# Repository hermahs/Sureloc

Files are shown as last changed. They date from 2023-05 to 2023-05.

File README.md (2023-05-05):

# SureLoc: Trust-Based Lending System

SureLoc is an open source project that provides a trust-based lending system for keeping track of who has taken out a certain physical item, called "SureLoc". The system allows users to borrow and lend SureLocs among themselves, while keeping a log of who has borrowed each item and for how long. This can help build trust and accountability among community members who share resources, especially in contexts where formal lending systems may not exist or may be difficult to access.

## Features

- User accounts: Users can create an account to participate in the lending system, and log in securely using their credentials.
- Item borrowing: Users can borrow SureLocs from other users, and keep track of who has borrowed each item.
- Item lending: Users can lend their own SureLocs to other users, and keep track of who has borrowed each item and for how long.
- Item history: The system keeps a log of all borrowing and lending activity for each SureLoc, including the borrower's name, the lending date, and the expected return date.
- Trust ratings: Users can rate each other based on their reliability as borrowers or lenders, and this rating can help other users decide whether to lend or borrow from them in the future.

## Technology

SureLoc is a student project that was developed using Arduino technology. The project uses RFID technology to identify the SureLocs, and an Arduino microcontroller to communicate with the RFID reader and log the borrowing and lending activity.

Please note that due to time constraints and limited resources, the project may not have all the features or functionality that a full-fledged system may have. However, we welcome contributions from anyone interested in helping to develop and improve SureLoc!

## Contributing

If you'd like to contribute to SureLoc, please take a look at our `CONTRIBUTING.md` file for guidelines on how to get started.

## License

SureLoc is licensed under the MIT License. See `LICENSE.md` for more information.

## Getting Started

To get started with SureLoc, follow these steps:

### Needed Components

Before you can use SureLoc, you'll need to gather the following components:

#### Control Box Components

| Component | Quantity |
|---|---:|
| Arduino Uno v3 | 1 |
| RC522 RFID Reader | 1 |
| 12v Power Adapter | 1 |
| Buck Converter | 1 |
| 100k ohm resistor | 1 |
| SD card module | 1 |
| SD card | 1 |
| Breadboard | 1 |
| Barrel jack | 1 |
| 16x2 LCD screen |  (optional) |
| Rotary encoder |  (optional) |

#### Lending Module Components

| Component | Quantity |
|---|---:|
| Arduino Pro Micro | 1 |
| Servo | 1 |
| Small push press button | 2 |
| Transistors | 2 |
| 10k ohm resistor | 2 |
| 1k ohm resistor | 2 |
| Breadboard | 1 |
| Loadcell 5kg |  (optional) x 4 |
| Loadcell amplifier |  (optional) x 4 |

#### Parts Needed to be Printed

The following parts need to be 3D printed or laser cut:

##### Shelf module

| Part | Quantity |
|---|---:|
| Frame Left | 1 |
| Frame Right | 1 |
| Lock Container | 1 |
| Moon lock | 1 |
| Gears | 2 |
| Frame Rails | 4 |
| Drawer Rails | 4 |
| Drawer | 2 |
| Drawer lock holder | 2 |
| Clips Large | 2 |
| Clips Small | 2 |
| Breadboard holder | 1 |

##### Control box

| Part | Quantity |
|---|---:|
| Top hull | 1 |
| Bottom plate | 1 |
| Front plate | 1 |
| Breadboard holder | 1 |
| RFID card reader | 1 |

Note that the box parts can also be laser cut in wood if you have the capability.

Please note that these components are not included in the SureLoc package and must be acquired separately.

## Assembly of the control box and shelf module

### Shelf Module Assembly Guide

1. Insert the clips into one side of the frame.
2. If you are using load cells, screw them into the frame with a little bit of space between them.
3. Insert the servo and moon lock into the lock container.
4. Screw the gears to the servo and moon lock.
5. Combine the frames with the lock container in the middle.
6. Add the rails to the frames.
7. Assemble the drawers.
8. Connect the wires and add the breadboard to the breadboard holder.

### Control Box Assembly Guide

1. Add the breadboard holder to the base plate.
2. Screw the RFID card reader into its holder on the front plate.
3. Attach the screen and rotary encoder to the front plate.
4. Add the buck converter and barrel jack for power.
5. Assemble the top hull over the base plate and screw together.

Note: This is a general guide for assembly and may not include all necessary steps.

## Assembly of the electrical systems

For the assembly of the electrical system, see the images below:

### Control Box

[Control Box Diagram](https://github.com/hermahs/Sureloc/blob/724dfc568ab8b7403ac2a49ec040952a4f51c85d/ControlBox%20Diagram.png)

### Shelf module

[Shelf Module Diagram](https://github.com/hermahs/Sureloc/blob/724dfc568ab8b7403ac2a49ec040952a4f51c85d/ShelfModule.png)

## Installing the Software

Once you have all the necessary components, you can install the SureLoc software on your Arduino microcontroller. To do this, follow these steps:

1. Download the SureLoc code from the GitHub repository.
2. Open the code in the Arduino IDE.
3. Connect the microcontroller to your computer via USB.
4. Upload the code to the microcontroller using the Arduino IDE.

## Support

If you encounter any issues or have questions about using SureLoc, please feel free to create a GitHub issue. We're here to help and improve the system together!

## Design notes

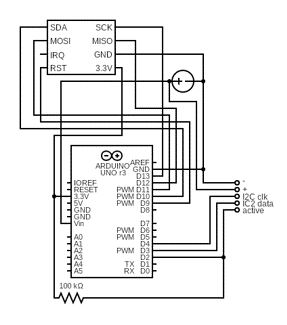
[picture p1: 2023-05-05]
ControlBox Diagram.png

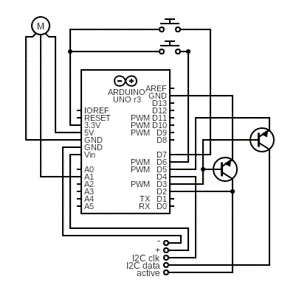
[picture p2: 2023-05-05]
ShelfModule.png

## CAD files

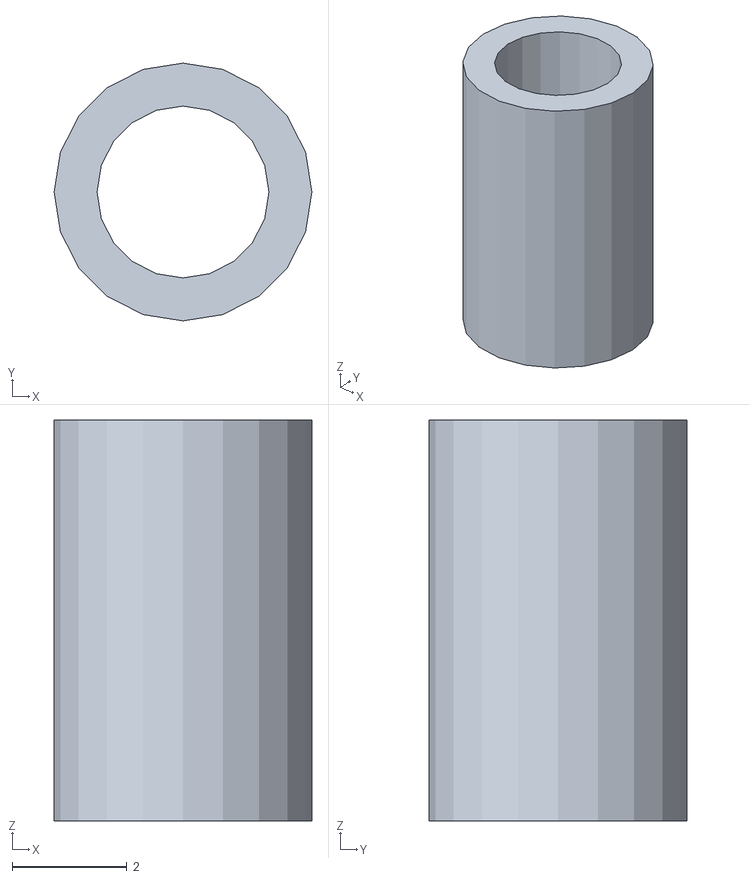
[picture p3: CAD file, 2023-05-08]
models/Control box/Spacers.stl
4.50 x 4.50 x 7.00

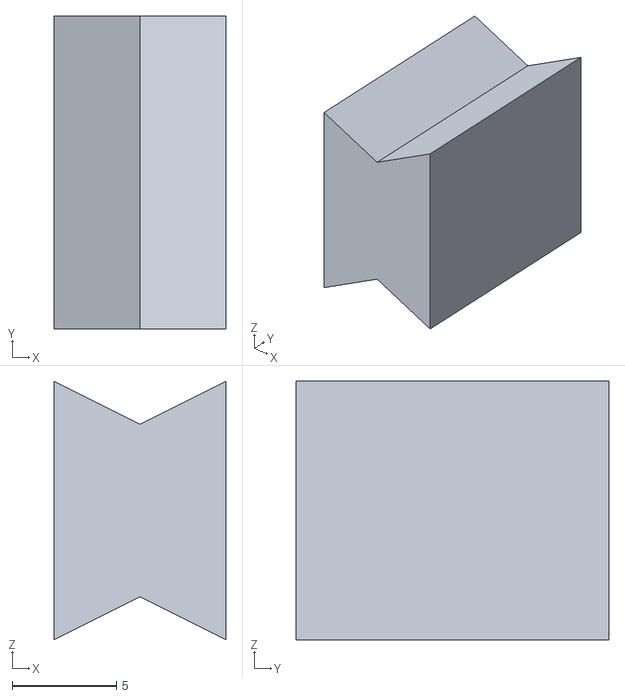
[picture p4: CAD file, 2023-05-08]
models/Shelf module/Wall Mount Rail Connector.stl
8.24 x 15.0 x 12.4

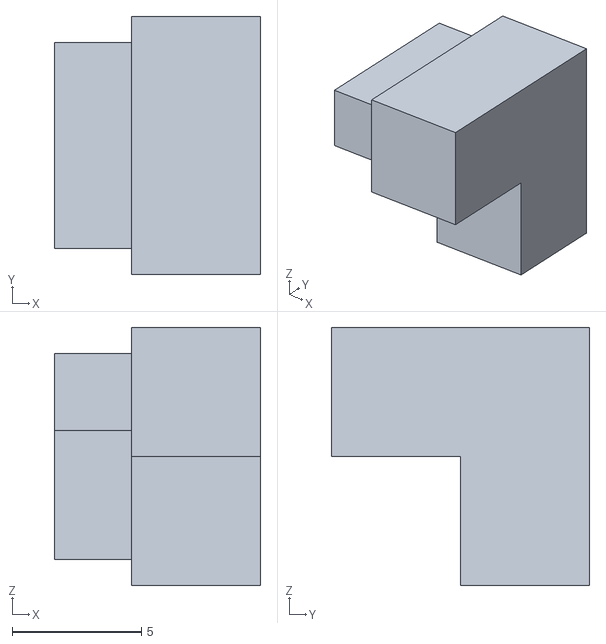
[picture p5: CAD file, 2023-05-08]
models/Shelf module/walls/Frame to Wall Connector.stl
8.00 x 10.0 x 10.0

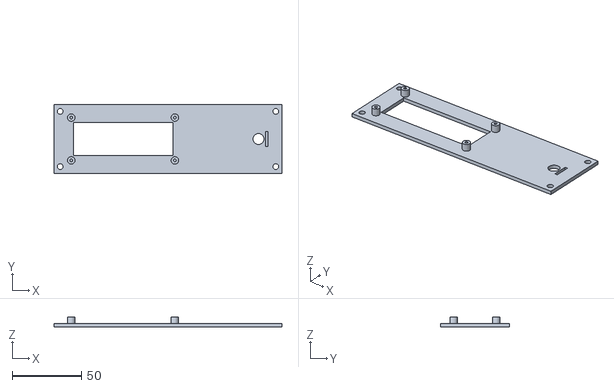
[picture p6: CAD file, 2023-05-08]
models/Control box/Front plate.stl
165.0 x 50.0 x 7.50

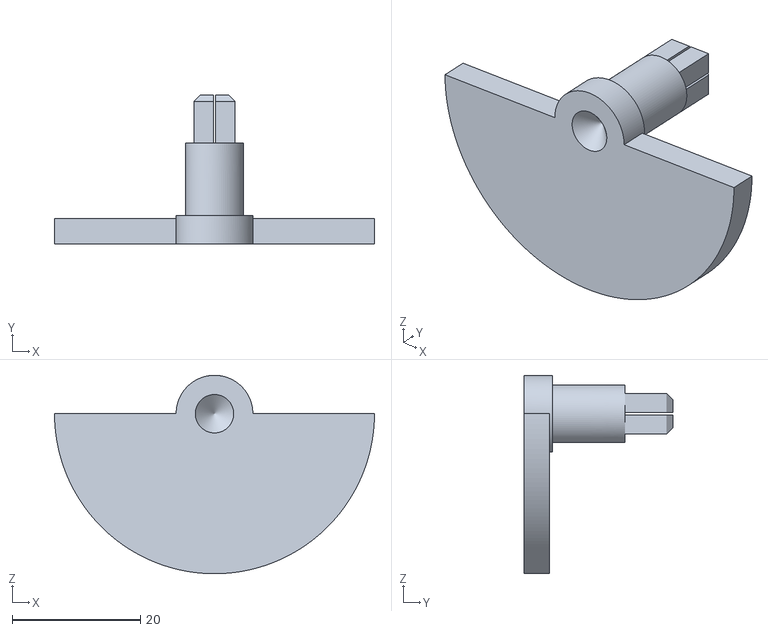
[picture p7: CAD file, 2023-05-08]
models/Shelf module/Moon Lock.stl
50.0 x 23.3 x 31.0

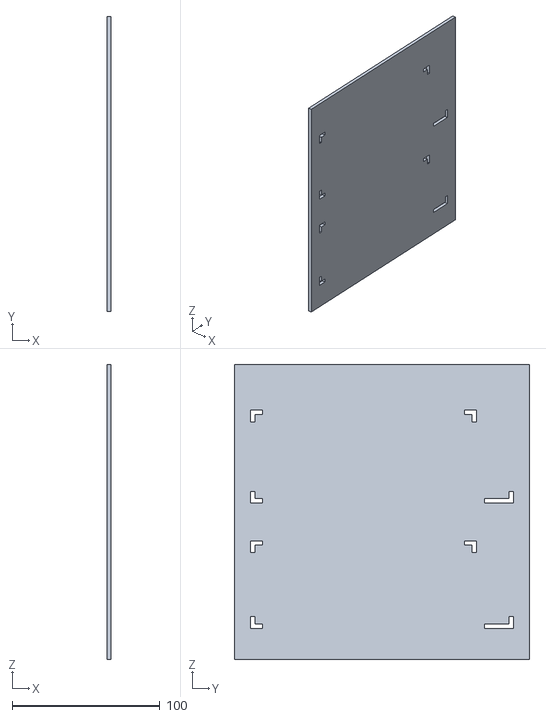
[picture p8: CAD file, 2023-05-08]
models/Shelf module/walls/Wall.stl
3.00 x 200.0 x 200.0

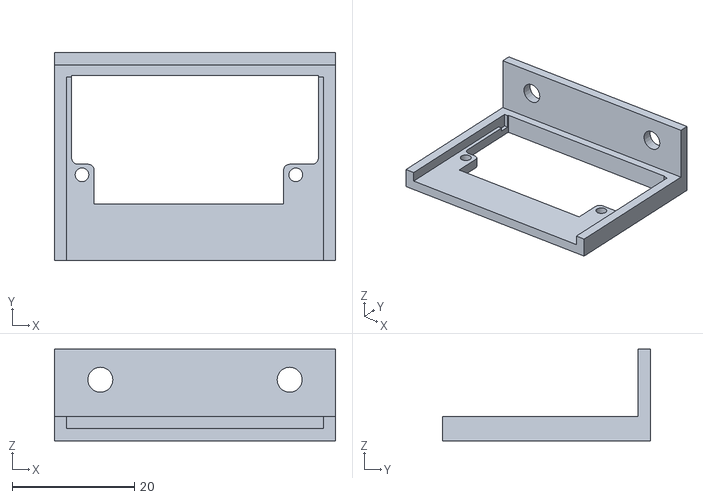
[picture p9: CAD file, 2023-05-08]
models/Control box/RFID Card reader.stl
46.0 x 34.0 x 15.0

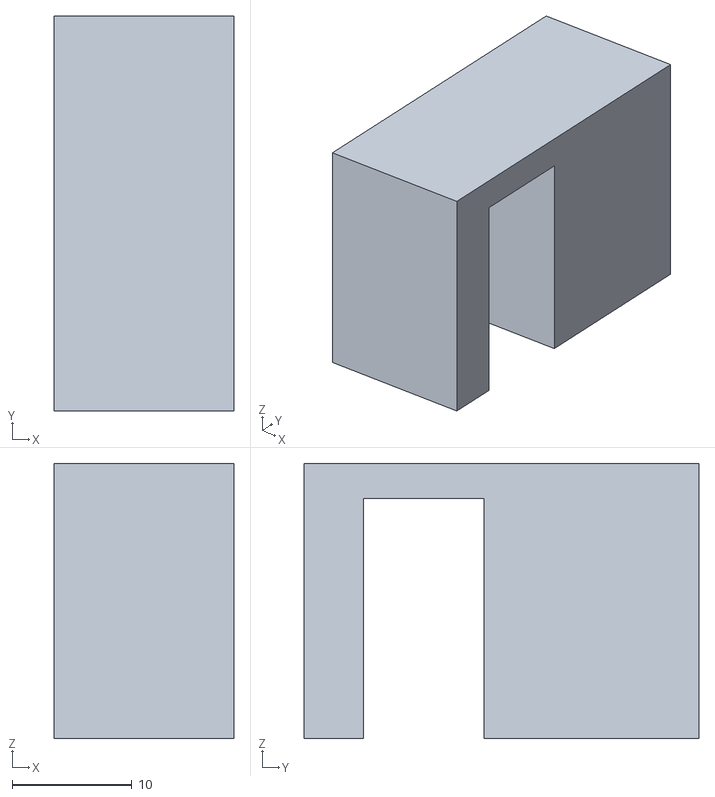
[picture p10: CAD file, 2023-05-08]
models/Shelf module/Wall Mount Bottom Support.stl
15.0 x 33.0 x 23.0

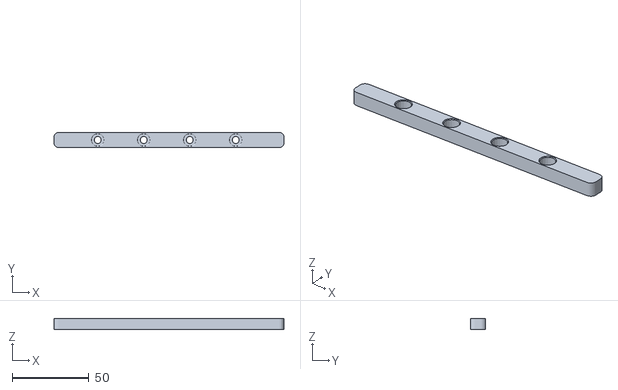
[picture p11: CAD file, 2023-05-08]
models/Control box/Connector Rails.stl
150.0 x 10.0 x 7.50

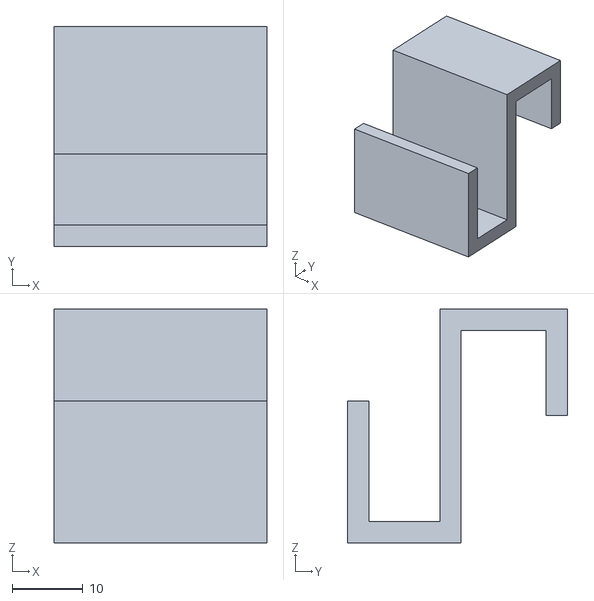
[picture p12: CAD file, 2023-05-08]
models/Shelf module/Wall Mount Clip.stl
30.0 x 31.0 x 33.0

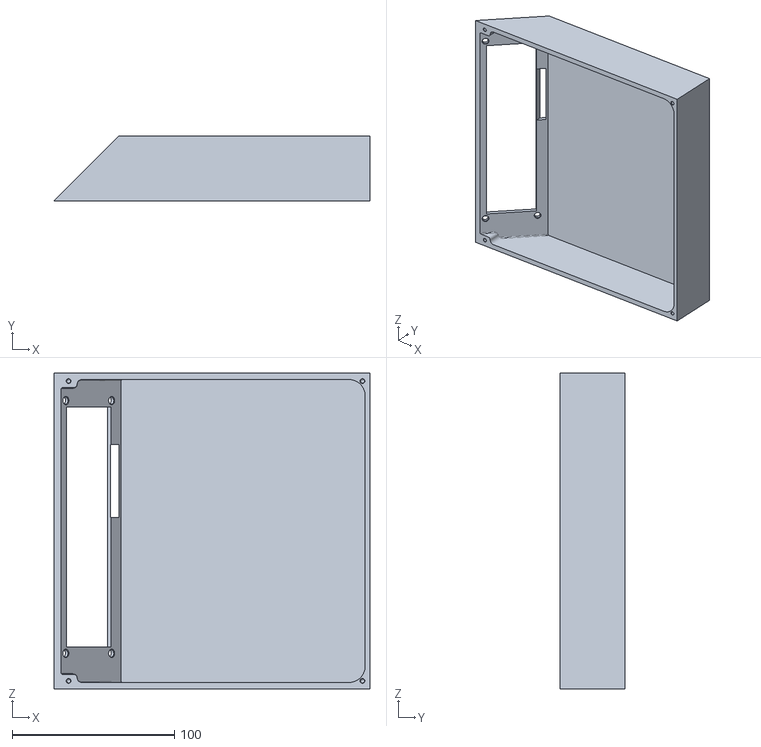
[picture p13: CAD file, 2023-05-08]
models/Control box/Top Hull.stl
195.0 x 40.0 x 195.0

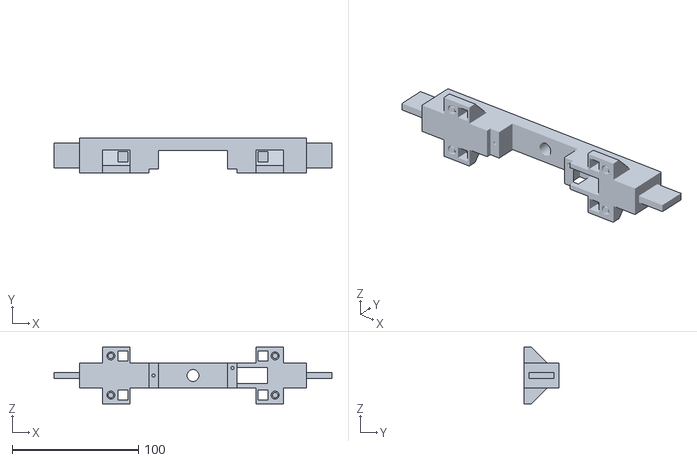
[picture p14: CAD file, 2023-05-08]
models/Shelf module/Lock Container.stl
220.0 x 28.0 x 45.0

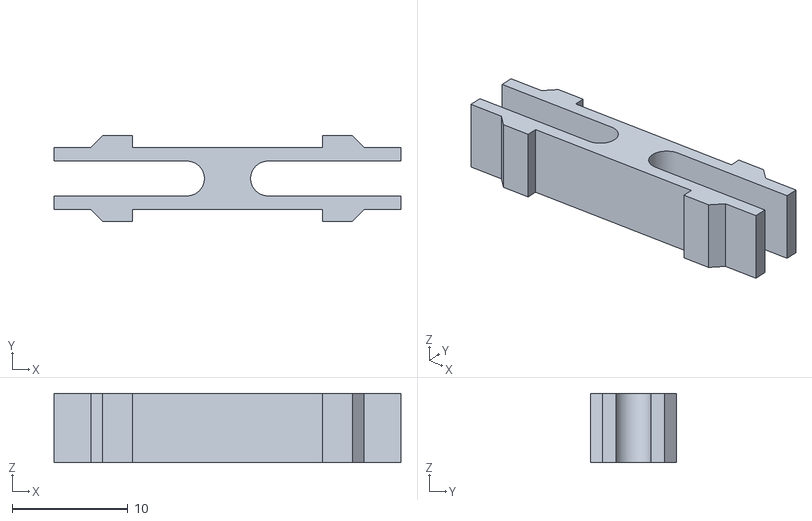
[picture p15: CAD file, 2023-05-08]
models/Shelf module/Clip Thin.stl
30.0 x 7.40 x 6.00

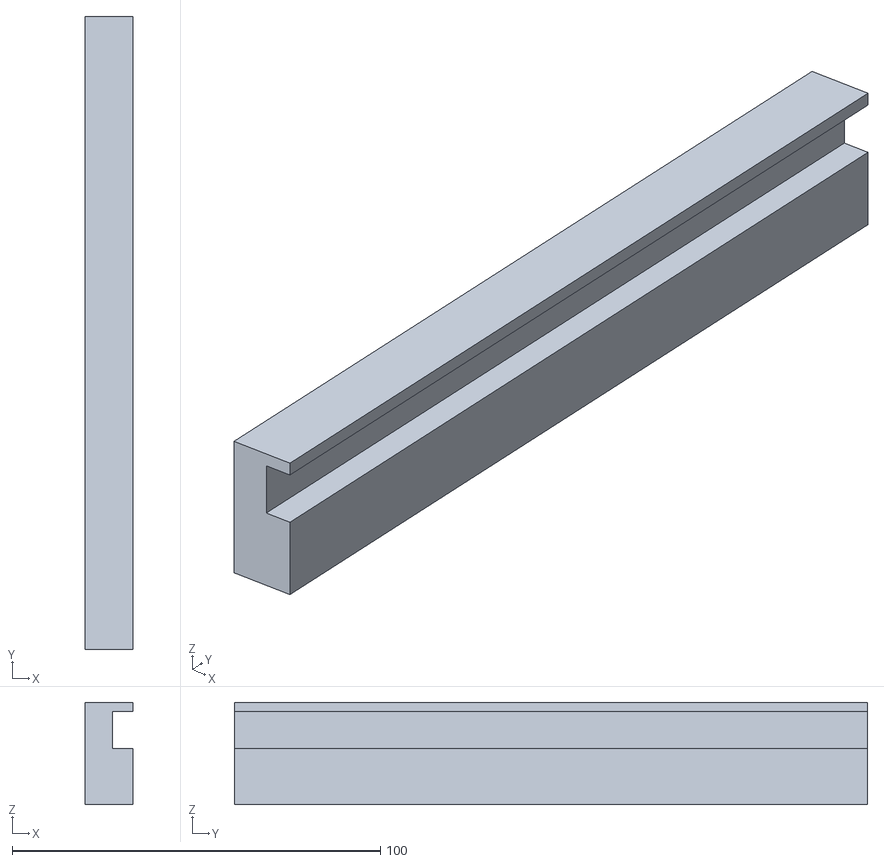
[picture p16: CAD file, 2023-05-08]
models/Shelf module/Rail Base.stl
13.0 x 172.0 x 27.8

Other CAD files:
models/Shelf module/Frame Clip Tool.stl
models/Shelf module/Clip Thick.stl
models/Shelf module/Wall Mount Rail.stl
models/Shelf module/Back stop.stl
models/Shelf module/Drawer Rail.stl
models/Shelf module/Rail Loadcell.stl

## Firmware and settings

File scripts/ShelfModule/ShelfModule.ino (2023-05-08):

#include <Wire.h>
#include <Servo.h>
#include <EEPROM.h>
#include <HX711.h>

#include "commands.h"

// pins 6-9 are buttons
// pins 1,2,3,10 are data
// A3 is Servo

// each weight requires 2 pins (+ ground and power)
// (16, 14), (15, 18), (19, 20), (4, 5)

#define signalPin 1
#define setActivePin 10
#define button1Pin 8
#define button2Pin 9
#define servoPin A3

#define eLocation 0

#define nrShelf 2

float calibration_factor = 400350;

Servo servo;

bool isActive = false;

byte openAddress = 0x0;
bool isOpen = false;

int signalVal;

int buttonVal1 = LOW;
int oldButtonVal1 = LOW;

int buttonVal2 = LOW;
int oldButtonVal2 = LOW;

byte address1 = 0xFF;
byte address2 = 0xFF;

byte action = 0x0;
byte activeAddress = 0x0;

char input;

bool actionCompleted = true;
unsigned long actionTime;
unsigned long now;

// start up protocol to get new address
void boot() {
  Serial.println("Booting");
  action = NEW;
  while (!checkAvailable()) {
    delay(10);
  }
  setActive();
}

// ends start up protocol
void finishBoot() {
  action = 0x0;
  unsetActive();
}

void handleOpen(int shelf) {
  if (nrShelf == 2) {
    switch (shelf) {
      case 1:
        servo.write(90 + 85);
        break;
      case 2:
        servo.write(90 - 85);
        break;
    }
  }
  isOpen = true;
  action = 0x0;
  activeAddress = 0x0;
  unsetActive();
}

void handleClose() {
  isOpen = false;
  action = 0x0;
  activeAddress = 0x0;
  servo.write(90);
  Serial.println("Closing");
  unsetActive();
}

// check if master is available to be communicated with
bool checkAvailable() {
  signalVal = digitalRead(signalPin);
  if (signalVal == HIGH) return true;
  return false;
}

// sets signalPin to LOW to tell master that data wants to be sent
void setActive() {
  if (!isActive) {
    digitalWrite(setActivePin, HIGH);
    isActive = true;
    actionCompleted = false;
    actionTime = millis();
  }
}

// sets signalPin to HIGH to tell other slaves that its open to communication
void unsetActive() {
  if (isActive) {
    digitalWrite(setActivePin, LOW);
    actionCompleted = true;
    actionTime = 0;
    isActive = false;
  }
}

void handleNotOK() {
  action = 0x0;
  activeAddress = 0x0;
  unsetActive();
}

// handle data requests from master
void handleRequest() {
  // need to send address to log box
  // need to check if we can open or not
  // open if we can, otherwise we cant
  Serial.println("Requested"); 
  byte message[2] = {0x00, 0x00};
  switch (action) {
    case NEW:
      message[0] = activeAddress;
      message[1] = NEW;
      Wire.write(message, sizeof(message));
      break;
    case OPEN:
      message[0] = activeAddress;
      message[1] = OPEN;
      Wire.write(message, sizeof(message));
      break;
    case CLOSE:
      message[0] = activeAddress;
      message[1] = CLOSE;
      Wire.write(message, sizeof(message));
      break;
  }
}

void handleReceive(int byteCount) {

  if (byteCount > 4) {
    Serial.print("We recieved many bytes: ");
    Serial.println(byteCount);
  }

  byte bytes[byteCount];

  int i = 0;
  while (Wire.available()) {
    bytes[i] = Wire.read();
    i++;
  }

  Serial.print("Got message: ");
  Serial.println(bytes[1]);

  switch (action) {
    case NEW:
      if (bytes[1] == ACK) {
        if (address1 == 0xFF && address2 == 0xFF) {
          address1 = bytes[0];
          // EEPROM.write(eLocation, address1);
          finishBoot();
        } else {
          address2 = bytes[0];
          finishBoot();
        }
      }
      break;

    case OPEN:
      if (bytes[1] == OK) {
        if (activeAddress == address1) handleOpen(1);
        else handleOpen(2);
      } else handleNotOK();
      break;

    case CLOSE:
      if (bytes[1] == OK) handleClose();
      else handleNotOK();
      break;
  }
}

void setup() {
  pinMode(signalPin, INPUT);
  pinMode(setActivePin, OUTPUT);
  pinMode(button1Pin, INPUT);
  pinMode(button2Pin, INPUT);
  digitalWrite(setActivePin, LOW);
  Wire.begin(1);
  Wire.onRequest(handleRequest);
  Wire.onReceive(handleReceive);
  Serial.begin(9600);
  servo.attach(servoPin);
  delay(6000);
  digitalWrite(setActivePin, LOW);
  Serial.println("Booting");
  servo.write(90);
  delay(1000);
}

void loop() {
  if (address1 == 0xFF && action != NEW) {
    Serial.println("booting 1");
    boot();
    return;
  }

  if (address2 == 0xFF && action != NEW) {
    Serial.println("booting 2");
    boot();
    return;
  }

  if (actionCompleted == false && (millis() - actionTime) > 3000) {
    Serial.println("We are unsetting active");
    unsetActive();
    delay(2500);
    action = 0x0;
  }

  // if (Serial.available()) {
  //   input = Serial.read();
  //   if (input == 'o') {
  //     if (!isOpen) {
  //       Serial.println("Trying to open box 1");
  //       if (checkAvailable()) {
  //         action = OPEN;
  //         activeAddress = address1;
  //         setActive();
  //       }
  //     } else {
  //       Serial.println("Trying to close box 1");
  //       if (checkAvailable()) {
  //         action = CLOSE;
  //         activeAddress = address1;
  //         setActive();
  //       }
  //     }
  //   } else if (input == 'p') {
  //     if (!isOpen) {
  //       Serial.println("Trying to open box 2");
  //       if (checkAvailable()) {
  //         action = OPEN;
  //         activeAddress = address2;
  //         setActive();
  //       }
  //     } else {
  //       Serial.println("Trying to close box 2");
  //       if (checkAvailable()) {
  //         action = CLOSE;
  //         activeAddress = address2;
  //         setActive();
  //       }
  //     }
  //   }
  // }


  buttonVal1 = digitalRead(button1Pin);
  buttonVal2 = digitalRead(button2Pin);

  if (buttonVal1 != oldButtonVal1) {
    oldButtonVal1 = buttonVal1;

    delay(50);
    buttonVal1 = digitalRead(button1Pin);
    if(buttonVal1 == HIGH) {
      Serial.println("Button 1 is pressed");
      if (!isOpen) {
        if (checkAvailable()) {
          action = OPEN;
          activeAddress = address1;
          setActive();
        }
      } else {
        if (checkAvailable()) {
          action = CLOSE;
          activeAddress = address1;
          setActive();
        }
      }
    }
  } 
  if (buttonVal2 != oldButtonVal2) {
    oldButtonVal2 = buttonVal2;

    delay(50);
    if (buttonVal2 == HIGH) {
      Serial.println("Button 2 is pressed");
      if (!isOpen) {
        if (checkAvailable()) {
          action = OPEN;
          activeAddress = address2;
          setActive();
        }
      } else {
        if (checkAvailable()) {
          action = CLOSE;
          activeAddress = address2;
          setActive();
        }
      }
    }
  }
}

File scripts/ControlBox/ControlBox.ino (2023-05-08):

#include <Wire.h>
#include <SPI.h>
#include <MFRC522.h>
#include <LiquidCrystal.h>

#include "commands.h"

#define signalPin 2
#define SS_PIN 10
#define RST_PIN 9
#define onPin 8

#define BOX 1

MFRC522 mfrc522(SS_PIN, RST_PIN);

LiquidCrystal lcd(6, 4, 14, 15, 16, 17);

bool active = false;
volatile int signalPinVal;

bool cardScanned = false;
bool boxOpen = false;

bool signalFlag = false;

byte openBoxId = 0x0;
String openUID;

byte nextId = 0x01;

String openBoxText = "Hi! Scan card to open box";

void handleAck() {}

// handles sending message to box
void sendMessage(byte id, byte m) {
  Serial.println("Sending message");
  byte message[2] = {id, m};
  Wire.beginTransmission(1);
  Wire.write(message, 2);
  Wire.endTransmission(1);
}

// handles addition of new box
void handleNewBox() {
  Serial.println("Creating new box");
  sendMessage(nextId, ACK);
  nextId++;
}

// handling the opening and closing of box
void handleOpenClose(byte id, bool open) {
  Serial.print("Trying to do something to box: ");
  Serial.print(id);
  Serial.print(" ");
  Serial.println(open);

  if (open) {
    if (!cardScanned) {
      sendMessage(id, NOT_OK);
      return;
    }

    if(boxOpen) {
      sendMessage(id, NOT_OK);
      return;
    }

    boxOpen = true;
    openBoxId = id;
    sendMessage(id, OK);
    Serial.print("Box open: ");
    Serial.println(openBoxId);
  } else {
    if (!cardScanned) {
      sendMessage(id, NOT_OK);
      return;
    }

    if(!boxOpen) {
      sendMessage(id, NOT_OK);
      return;
    }

    if(id != openBoxId) {
      sendMessage(id, NOT_OK);
      return;
    }

    boxOpen = false;
    cardScanned = false;
    Serial.print("Closing box: ");
    Serial.println(openBoxId);
    openBoxId = 0x0;
    openUID = "";
    sendMessage(id, OK);
  }
}

void handleWeight() {

}


void handleCalibrate() {
  // Calibrate -> select calibrate, then select box/open box

}

void getMessage() {
  Wire.clearWireTimeoutFlag();
  Serial.write("Getting message\n");
  // delay(1000);
  // send data to box first, then get what it is trying to do
  // only request the first 2 bytes, one for Id, other for command, and the last 2 for general data
  byte bytes[4];

  byte len = Wire.requestFrom(BOX, 4);
  Serial.println("we have sent request");
  Serial.print("is wire available? ");
  Serial.println(Wire.available());
  Serial.print("data we got: ");
  if (len == 0) {
    Serial.println("Error occured while requesting");
    if (Wire.getWireTimeoutFlag())
      Serial.println("Timeout error");
  } else {
    int i = 0;
    while(Wire.available()) {
      bytes[i] = Wire.read();
      i++;
    }
    Serial.println("");
    Serial.print("Command: ");
    Serial.println(bytes[1]);

    // handle command here
    switch(bytes[1]) {
      case NEW:
        handleNewBox();
        break;
        
      case CLOSE:
        handleOpenClose(bytes[0], false);
        break;

      case OPEN:
        handleOpenClose(bytes[0], true);
        break;

      case ACK:
        handleAck();
        break;

      case WEIGHT:
        handleWeight();
        break;
      
      case CALIBRATE:
        handleCalibrate();
        break;
        
      default:
        // Something happened that shouldn't and we could not understand what we should do.
        Serial.println("Default occured");
        break;
    }
  }
  signalFlag = false;
}

// void printHiOpenBox() {
//   lcd.clear();
//   lcd.print("Yeet");
//   // lcd.setCursor(0,1);
//   // lcd.print("open box.");
// }

// void printPushBoxToOpen() {
//   lcd.clear();
//   lcd.print("Press a box to");
//   lcd.setCursor(0,1);
//   lcd.print("open.");
// }

// void printOpenBox() {
//   lcd.clear();
//   lcd.print("Box open: ");
//   lcd.print(openBoxId);
// }

void interruptFunc() {
  signalFlag = true;
}

void setup() {
  Serial.begin(500000);
  delay(1500);
  Serial.println("Setup");
  delay(1500);
  pinMode(onPin, OUTPUT);
  pinMode(signalPin, INPUT_PULLUP);
  attachInterrupt(digitalPinToInterrupt(signalPin), interruptFunc, FALLING);
  SPI.begin();
  mfrc522.PCD_Init();
  lcd.begin(16, 2);
  delay(40);
  lcd.clear();
  lcd.print("hello");
  Wire.begin();
  Wire.setWireTimeout(2500000, false);
  digitalWrite(onPin, HIGH);
}

void loop() {
  // if (!boxOpen && !cardScanned) printHiOpenBox();
  // else if (!boxOpen && cardScanned) printPushBoxToOpen();
  // else printOpenBox();

  if (signalFlag) getMessage();

  if (!cardScanned) {
    if (! mfrc522.PICC_IsNewCardPresent())
      return;
    if (! mfrc522.PICC_ReadCardSerial())
      return;

    Serial.print("UID tag:");
    byte letter;
    for (byte i = 0; i < mfrc522.uid.size; i++) {
      openUID.concat(String(mfrc522.uid.uidByte[i] < 0x10 ? " 0" : " "));
      openUID.concat(String(mfrc522.uid.uidByte[i], HEX));
    }
    Serial.println(openUID);
    cardScanned = true;
  }
}
